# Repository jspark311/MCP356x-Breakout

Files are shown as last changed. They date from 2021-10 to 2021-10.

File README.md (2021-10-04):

# MCP3564-Breakout

A breakout board for Microchip's 24-bit SPI ADC. The MCP3564 is a 24-bit sigma-delta ADC with support for up to eight single-ended, or four differential channels. It supports extensive oversampling depths, flexible MUX front-end, circuit burnout detection, adjustable gain, Vref from [0v - 3.6v], and optional internal oscillator.

#### [Hackaday.io Page](https://hackaday.io/project/168371-mcp3564-breakout)

#### [Order from Tindie](https://www.tindie.com/products/24263/)

------------------------

### What is in this repository:

**./doc**:  Location for documentation

**./KiCAD**:  Hardware design files

**./Arduino**:  Arduino driver

------------------------

Front (With OSC) | Back (With OSC)
:-------:|:------:
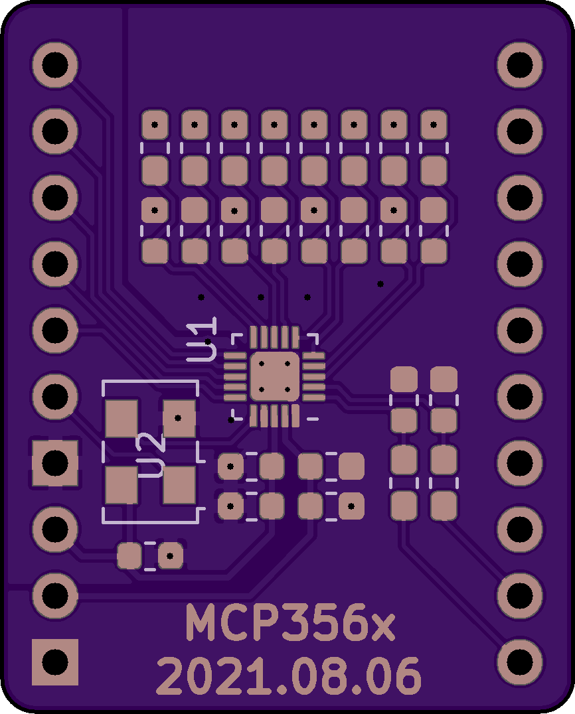
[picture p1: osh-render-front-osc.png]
Front
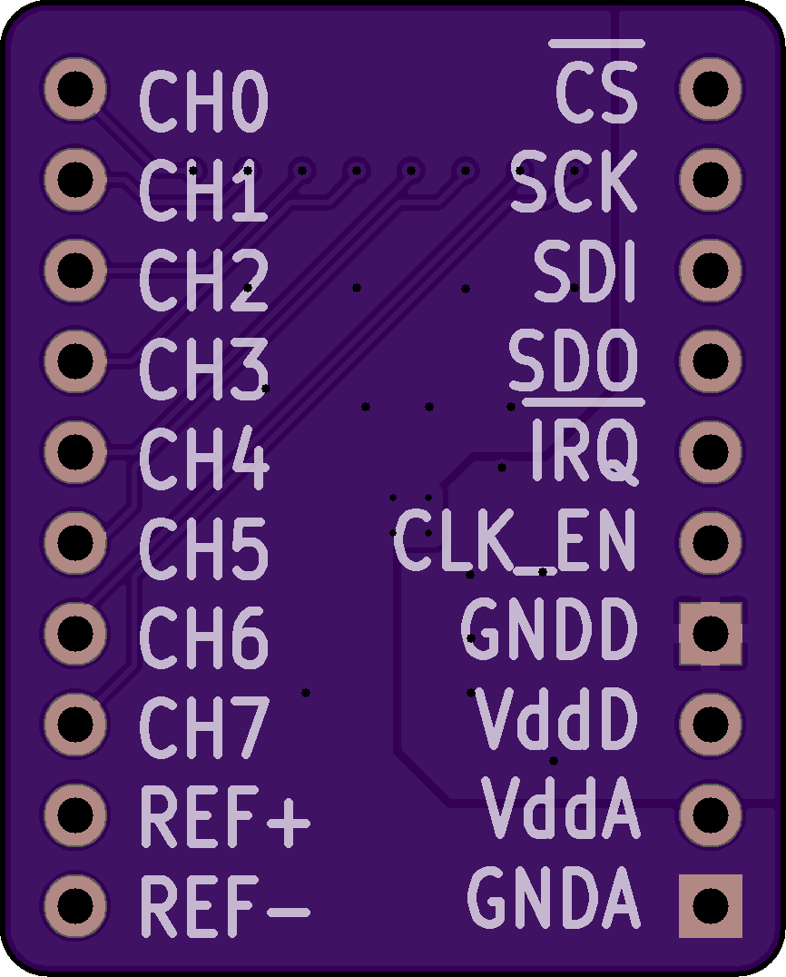
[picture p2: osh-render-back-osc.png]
Back
  | 
Front (No OSC) | Back (No OSC)
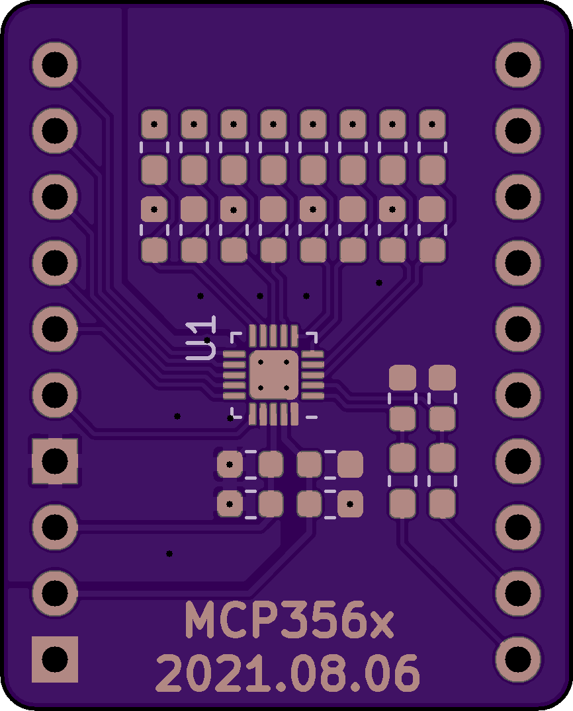
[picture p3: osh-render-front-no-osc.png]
Front
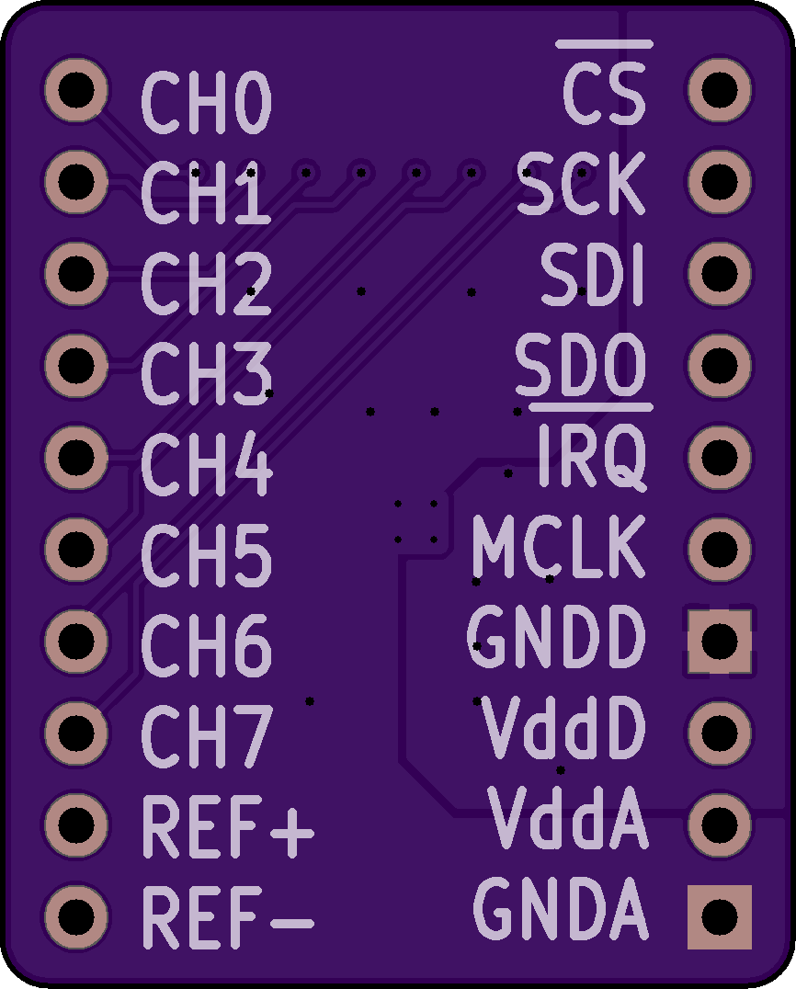
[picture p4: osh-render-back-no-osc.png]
Back
  | 

[](https://oshpark.com/shared_projects/TIq4K8iz)

[](https://oshpark.com/shared_projects/fjlkMb7V)

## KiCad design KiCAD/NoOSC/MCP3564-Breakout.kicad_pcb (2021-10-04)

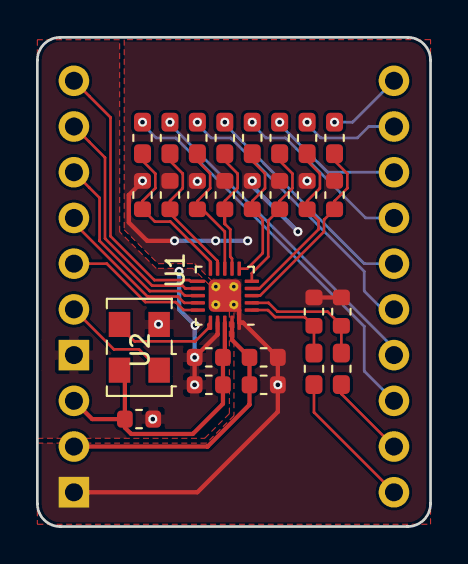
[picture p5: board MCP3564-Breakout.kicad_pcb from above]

Board: 2 copper layers, 21.8 x 27.2 mm, 29 parts (0 on the bottom side), 31 nets.

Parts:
C0, C1, C2, C3, C4, C5, C6, C7, C11, C12: 0.1uF; C_0603_1608Metric
C8, C9, C10, C13, C14: 10uF; C_0603_1608Metric
J2, J3: Conn_01x08_Male; PinHeader_1x10_P2.54mm_Vertical
R0, R1, R2, R3, R4, R5, R6, R7, R8, R9: 100; R_0603_1608Metric_Pad1.05x0.95mm_HandSolder
U1: MCP3964; QFN-20-1EP_3x3mm_P0.45mm_EP1.6x1.6mm_ThermalVias
U2: 19.6608MHz OSC; Oscillator_SMD_EuroQuartz_XO53-4Pin_5.0x3.2mm

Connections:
/CH0: J3.1, R0.1
/CH1: J3.2, R1.1
/CH2: J3.3, R2.1
/CH3: J3.4, R3.1
/CH4: J3.5, R4.1
/CH5: J3.6, R5.1
/CH6: J3.7, R6.1
/CH7: J3.8, R7.1
/GNDA: C0.2, C1.2, C2.2, C3.2, C4.2, C5.2, C6.2, C7.2, C8.2, C11.1, C13.2, C14.1, J2.1, U1.20, U1.21
/GNDD: C9.2, C10.2, C12.1, J2.4, U1.17, U2.2
/MCLK: U1.16, U2.3
/OSC_EN: J2.5, U2.1
/REFIN+: C14.2, R8.2, U1.2
/REFIN-: C13.1, R9.2, U1.1
/SCK: J2.9, U1.12
/SDI: J2.8, U1.13
/SDO: J2.7, U1.14
/VddA: C8.1, C11.2, J2.2, U1.19
/VddD: C9.1, C10.1, C12.2, J2.3, U1.18, U2.4
/~CS: J2.10, U1.11
/~IRQ: J2.6, U1.15
unnamed: C0.1, R0.2, U1.3
unnamed: C1.1, R1.2, U1.4
unnamed: C2.1, R2.2, U1.5
unnamed: C3.1, R3.2, U1.6
unnamed: C4.1, R4.2, U1.7
unnamed: C5.1, R5.2, U1.8
unnamed: C6.1, R6.2, U1.9
unnamed: C7.1, R7.2, U1.10
unnamed: J3.9, R8.1
unnamed: J3.10, R9.1

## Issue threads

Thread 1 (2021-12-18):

StringBuilder.h is missing

karelchik, 2021-12-18:
Hello,

We wish to use your library, but "StringBuilder.h" is missing. Any leads?

All the best

jspark311, 2022-02-23:
It depends on _how_ you are going to use the driver.
If you cloned it from github, and don't want the debugging, you can simply open the driver files and remove any lines that contain `StringBuilder`.

If you want the debugging messages, and you are under Arduino, you can use the library manager to install `CppPotpourri`, which is the library that contains the StringBuilder class.

hbotzombie, 2022-04-19:
I have the same issue as above and tried using your MCP356x-Example code to try and understand the ADC chip better but came up against the same 'StringBuilder.h" missing issue. I added the CppPotpourri to invoke the String Builder but kept the original MCP356x library under the MCP356x Breakout folder but there are lots of compile errors associated with the 'class SPIClass'.

I have also tried the MCP356x library under ManuvrDrivers-master with no luck. Any ideas what I'm doing wrong?

jspark311, 2022-07-04:
There are two version of the driver. The one in ManuvrDrivers is the one that I actually build things with. It is non-blocking and interrupt-driven. Getting it to work is fairly involved, but if you want high data rates, it's probably worth it.

There is also the simple vanilla Arduino driver (the one in this repo), which is probably the better choice if you are going to rip up or re-author the software anyhow. It is blocking, doesn't need CppPotpourri, and is generally easier to understand.
https://github.com/jspark311/MCP356x-Breakout/tree/master/Arduino

Please review this thread for support going forward. I'm not very responsive on github, and this ground has been covered here:
https://hackaday.io/messages/room/298450

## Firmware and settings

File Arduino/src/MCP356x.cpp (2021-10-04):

/*
File:   MCP356x.cpp
Author: J. Ian Lindsay
*/

#include "MCP356x.h"

/*******************************************************************************
*      _______.___________.    ___   .___________. __    ______     _______.
*     /       |           |   /   \  |           ||  |  /      |   /       |
*    |   (----`---|  |----`  /  ^  \ `---|  |----`|  | |  ,----'  |   (----`
*     \   \       |  |      /  /_\  \    |  |     |  | |  |        \   \
* .----)   |      |  |     /  _____  \   |  |     |  | |  `----.----)   |
* |_______/       |__|    /__/     \__\  |__|     |__|  \______|_______/
*
* Static members and initializers should be located here.
*******************************************************************************/
// We can have up to four of these in a given system.
#define MCP356X_MAX_INSTANCES    2
volatile static MCP356x* INSTANCES[MCP356X_MAX_INSTANCES] = {0, };

static SPISettings spi_settings(12000000, MSBFIRST, SPI_MODE0);  // Max is 20MHz

/* Register widths in bytes. Index corresponds directly to register address. */
static const uint8_t MCP356x_reg_width[16] = {
  1, 1, 1, 1, 1, 1, 1, 3, 3, 3, 3, 3, 1, 1, 2, 2
};

static const uint16_t OSR1_VALUES[16] = {
  1, 1, 1, 1, 1, 2, 4, 8, 16, 32, 40, 48, 80, 96, 160, 192
};

static const uint16_t OSR3_VALUES[16] = {
  32, 64, 128, 256, 512, 512, 512, 512, 512, 512, 512, 512, 512, 512, 512, 512
};

static const char* CHAN_NAMES[16] = {
  "SE_0", "SE_1", "SE_2", "SE_3", "SE_4", "SE_5", "SE_6", "SE_7",
  "DIFF_A", "DIFF_B", "DIFF_C", "DIFF_D", "TEMP", "AVDD", "VCM", "OFFSET"
};

/*
* This is an ISR.
*/
void mcp356x_isr0() {
  ((MCP356x*) INSTANCES[0])->isr_fired = true;
}

/*
* This is an ISR.
*/
void mcp356x_isr1() {
  ((MCP356x*) INSTANCES[1])->isr_fired = true;
}



/*******************************************************************************
*   ___ _              ___      _ _              _      _
*  / __| |__ _ ______ | _ ) ___(_) |___ _ _ _ __| |__ _| |_ ___
* | (__| / _` (_-<_-< | _ \/ _ \ | / -_) '_| '_ \ / _` |  _/ -_)
*  \___|_\__,_/__/__/ |___/\___/_|_\___|_| | .__/_\__,_|\__\___|
*                                          |_|
* Constructors/destructors, class initialization functions and so-forth...
*******************************************************************************/

/*
* Constructor. Delegated.
*/
MCP356x::MCP356x(uint8_t irq_pin, uint8_t cs_pin, uint8_t mclk_pin) :
  MCP356x(irq_pin, cs_pin, mclk_pin, 0x01) {}

/*
* Constructor specifying device address.
*/
MCP356x::MCP356x(uint8_t irq_pin, uint8_t cs_pin, uint8_t mclk_pin, uint8_t addr) :
  _IRQ_PIN(irq_pin), _CS_PIN(cs_pin), _MCLK_PIN(mclk_pin), _DEV_ADDR(addr)
{
  bool unslotted = true;
  for (uint8_t i = 0; i < MCP356X_MAX_INSTANCES; i++) {
    if (unslotted) {
      if (nullptr == INSTANCES[i]) {
        _slot_number = i;
        INSTANCES[_slot_number] = this;
        unslotted = false;
      }
    }
  }
}


/*
* Destructor
*/
MCP356x::~MCP356x() {
  if (255 != _IRQ_PIN) {
    detachInterrupt(digitalPinToInterrupt(_IRQ_PIN));
  }
  INSTANCES[_slot_number] = nullptr;
}


/*
* Send the fastcommand to bounce the ADC.
* Returns...
*   -2 if refresh found unexpected values.
*   -1 if there was a problem writing the reset command or refreshing the registers.
*   0  if reset command was sent successfully.
*/
int8_t MCP356x::reset() {
  int8_t ret = _send_fast_command(0x38);
  if (0 == ret) {
    delay(75);   // <--- Arbitrary delay value
    digitalWrite(_CS_PIN, 0);
    digitalWrite(_CS_PIN, 1);
    digitalWrite(_CS_PIN, 0);
    digitalWrite(_CS_PIN, 1);   // Twiddle the CS line to ensure SPI reset.
    ret = _clear_registers();
    if (0 == ret) {
      delay(75);   // <--- Arbitrary delay value
      ret = refresh();
    }
  }
  return ret;
}


/*
* Resets the chip and writes our default configuration.
* Returns...
*   -7 if offset cal failed.
*   -6 if clock detection failed.
*   -5 if register refresh failed.
*   -4 if pin setup failed.
*   -3 if bad bus reference.
*   -2 if reset failed.
*   -1 if clock detection or calibration failed for some reason.
*   0  on success.
*/
int8_t MCP356x::init(SPIClass* b) {
  int8_t pin_setup_ret = _ll_pin_init();  // Configure the pins if they are not already.
  int8_t ret = -4;
  if (pin_setup_ret >= 0) {
    ret = -3;
    if (nullptr != b) {
      ret = -2;
      _bus = b;
      if (0 == reset()) {
        ret = -5;
        if (0 == _post_reset_fxn()) {
          if (!_mclk_in_bounds()) {   // Need to detect MCLK...
            ret = -6;
            int8_t det_ret = _detect_adc_clock();
            switch (det_ret) {
              case -3:    break;  // -3 if the class isn't ready for this measurement.
              case -2:    break;  // -2 if measurement timed out.
              case -1:    break;  // -1 if there was some mechanical problem communicating with the ADC
              case 0:     break;  // 0  if a clock signal within expected range was determined
              case 1:     break;  // 1  if we got a clock rate that was out of bounds or appears nonsensical
              default:    break;
            }
            //Serial.print("_detect_adc_clock returned ");
            //Serial.println(det_ret);
          }
          if (_mclk_in_bounds()) {
            switch (_calibrate_offset()) {
              case 0:   ret = 0;    break;
              default:  ret = -7;   break;
            }
          }
        }
      }
    }
  }
  return ret;
}


/*
* Sets some of the more specialized features of the chip.
* Pass as an argument a select combination of flags defined in the
*   header file.
* NOTE: This fxn must be called ahead of first init(), since our
*   pin configuration might be in conflict with ADC configuration
*   otherwise.
* Returns...
*   -1 if called too late for a provided option.
*   0  on success.
*/
int8_t MCP356x::setOption(uint32_t flgs) {
  int8_t ret = 0;
  if (flgs & MCP356X_FLAG_USE_INTERNAL_CLK) {
    if (!(_mcp356x_flag(MCP356X_FLAG_PINS_CONFIGURED))) {
      // Only allow this change if the pins are not yet configured.
      _mcp356x_set_flag(MCP356X_FLAG_USE_INTERNAL_CLK);
      _mcp356x_clear_flag(MCP356X_FLAG_GENERATE_MCLK);
    }
    else {
      ret = -1;
    }
  }
  if (flgs & MCP356X_FLAG_GENERATE_MCLK) {
    if (!(_mcp356x_flag(MCP356X_FLAG_PINS_CONFIGURED))) {
      // Only allow this change if the pins are not yet configured.
      _mcp356x_set_flag(MCP356X_FLAG_GENERATE_MCLK);
      _mcp356x_clear_flag(MCP356X_FLAG_USE_INTERNAL_CLK);
    }
    else {
      ret = -1;
    }
  }
  if (flgs & MCP356X_FLAG_3RD_ORDER_TEMP) {
    _mcp356x_set_flag(MCP356X_FLAG_3RD_ORDER_TEMP);
  }
  return ret;
}
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

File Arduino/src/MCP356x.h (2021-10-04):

#ifndef __MCP356x_H__
#define __MCP356x_H__

#include <inttypes.h>
#include <stdint.h>
#include <stdarg.h>
#include <SPI.h>
#include "StringBuilder.h"

/* In this case, these enum values translate directly to register addresses. */
enum class MCP356xRegister : uint8_t {
  ADCDATA   = 0x00,   // (it's complicated)  R
  CONFIG0   = 0x01,   // 8-bit               RW
  CONFIG1   = 0x02,   // 8-bit               RW
  CONFIG2   = 0x03,   // 8-bit               RW
  CONFIG3   = 0x04,   // 8-bit               RW
  IRQ       = 0x05,   // 8-bit               RW
  MUX       = 0x06,   // 8-bit               RW
  SCAN      = 0x07,   // 24-bit              RW
  TIMER     = 0x08,   // 24-bit              RW
  OFFSETCAL = 0x09,   // 24-bit              RW
  GAINCAL   = 0x0A,   // 24-bit              RW
  RESERVED0 = 0x0B,   // 24-bit              RW
  RESERVED1 = 0x0C,   // 8-bit               RW
  LOCK      = 0x0D,   // 8-bit               RW
  RESERVED2 = 0x0E,   // 16-bit              RW
  CRCCFG    = 0x0F    // 16-bit              R
};

/* The ADC is divided into 16 logical channels. */
enum class MCP356xChannel : uint8_t {
  SE_0   = 0x00,
  SE_1   = 0x01,
  SE_2   = 0x02,
  SE_3   = 0x03,
  SE_4   = 0x04,
  SE_5   = 0x05,
  SE_6   = 0x06,
  SE_7   = 0x07,
  DIFF_A = 0x08,
  DIFF_B = 0x09,
  DIFF_C = 0x0A,
  DIFF_D = 0x0B,
  TEMP   = 0x0C,  // Internal temperature sensor.
  AVDD   = 0x0D,  //
  VCM    = 0x0E,
  OFFSET = 0x0F
};

/* Conversion modes */
enum class MCP356xMode : uint8_t {
  ONESHOT_SHUTDOWN = 0,
  ONESHOT_STANDBY  = 2,
  CONTINUOUS       = 3
};

/* ADC gain ratio. Enum values convert directly into register values. */
enum class MCP356xGain : uint8_t {
  GAIN_ONETHIRD = 0,
  GAIN_1        = 1,
  GAIN_2        = 2,
  GAIN_4        = 3,
  GAIN_8        = 4,
  GAIN_16       = 5,
  GAIN_32       = 6,
  GAIN_64       = 7
};

/* Bias current. Enum values convert directly into register values. */
enum class MCP356xBiasCurrent : uint8_t {
  HALF      = 0,
  TWOTHIRDS = 1,
  ONE       = 2,
  DOUBLE    = 3
};

/* Enum value converts directly into register value.*/
enum class MCP356xBiasBoost : uint8_t {
  HALF      = 0,
  TWOTHIRDS = 1,
  ONE       = 2,
  DOUBLE    = 3
};

/* Enum values convert directly into register values. */
enum class MCP356xOversamplingRatio : uint8_t {
  OSR_32    = 0x00,
  OSR_64    = 0x01,
  OSR_128   = 0x02,
  OSR_256   = 0x03,  // Default on reset.
  OSR_512   = 0x04,
  OSR_1024  = 0x05,
  OSR_2048  = 0x06,
  OSR_4096  = 0x07,
  OSR_8192  = 0x08,
  OSR_16384 = 0x09,
  OSR_20480 = 0x0A,
  OSR_24576 = 0x0B,
  OSR_40960 = 0x0C,
  OSR_49152 = 0x0D,
  OSR_81920 = 0x0E,
  OSR_98304 = 0x0F
};

/* Clock prescaler options. */
enum class MCP356xAMCLKPrescaler : uint8_t {
  OVER_1 = 0,
  OVER_2 = 1,
  OVER_4 = 2,
  OVER_8 = 3
};


/*
* Class flags.
* NOTE: MCP356X_FLAG_USE_INTERNAL_CLK takes priority over
*   MCP356X_FLAG_GENERATE_MCLK to avoid potential pin contention. If both flags
*   are set, the MCLK pin (if given) will be configured as an input, and the
*   flag directing the class to generate a clock on that pin will be ignored.
*/
#define MCP356X_FLAG_DEVICE_PRESENT   0x00000001  // Part is likely an MCP356x.
#define MCP356X_FLAG_PINS_CONFIGURED  0x00000002  // Low-level pin setup is complete.
#define MCP356X_FLAG_INITIALIZED      0x00000004  // Registers are initialized.
#define MCP356X_FLAG_CALIBRATED       0x00000008  // ADC is calibrated.
#define MCP356X_FLAG_VREF_DECLARED    0x00000010  // The application has given us Vref.
#define MCP356X_FLAG_CRC_ERROR        0x00000020  // The chip has reported a CRC error.
#define MCP356X_FLAG_USE_INTERNAL_CLK 0x00000040  // The chip should use its internal oscillator.
#define MCP356X_FLAG_MCLK_RUNNING     0x00000080  // MCLK is running.
#define MCP356X_FLAG_SAMPLED_AVDD     0x00000100  // This calibration-related channel was sampled.
#define MCP356X_FLAG_SAMPLED_VCM      0x00000200  // This calibration-related channel was sampled.
#define MCP356X_FLAG_SAMPLED_OFFSET   0x00000400  // This calibration-related channel was sampled.
#define MCP356X_FLAG_3RD_ORDER_TEMP   0x00000800  // Spend CPU to make temperature conversion more accurate?
#define MCP356X_FLAG_GENERATE_MCLK    0x00001000  // MCU is to generate the clock.
#define MCP356X_FLAG_HAS_INTRNL_VREF  0x00004000  // This part was found to support an internal Vref.
#define MCP356X_FLAG_USE_INTRNL_VREF  0x00008000  // Internal Vref should be enabled.

// Bits to preserve through reset.
#define MCP356X_FLAG_RESET_MASK  (MCP356X_FLAG_DEVICE_PRESENT | MCP356X_FLAG_PINS_CONFIGURED | \
                                  MCP356X_FLAG_VREF_DECLARED | MCP356X_FLAG_USE_INTERNAL_CLK | \
                                  MCP356X_FLAG_3RD_ORDER_TEMP | MCP356X_FLAG_GENERATE_MCLK | \
                                  MCP356X_FLAG_HAS_INTRNL_VREF | MCP356X_FLAG_USE_INTRNL_VREF)

// Bits indicating calibration steps.
#define MCP356X_FLAG_ALL_CAL_MASK  (MCP356X_FLAG_SAMPLED_AVDD | \
                                    MCP356X_FLAG_SAMPLED_VCM | \
                                    MCP356X_FLAG_SAMPLED_OFFSET)
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

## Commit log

2021-10-04 Updating entire project.
    [MCP3564-Breakout.kicad_pcb, MCP3564-Breakout.sch]
2021-10-04 Updating Arduino library to support the MCP3564R.
